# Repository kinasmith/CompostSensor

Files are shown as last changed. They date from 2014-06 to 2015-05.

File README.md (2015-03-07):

# Compost Sensor

> Compost Sensor is an open source sensor system for monitoring and recording the temperature and moisture of active compost. It is for small scale commercial composting operations to help with quality control and the certification processes.

This is a currently work in progress. Blog updates can be found [here](http://www.kinasmith.com/itp/spring2015/thesis/).

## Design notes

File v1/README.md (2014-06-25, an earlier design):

Wireless Temperature Sensor Network for logging and automating medium scale composting operations.

Communication uses the HopeRF RFM12B radio modules on a custom shield designed by Andy Sigler:
https://github.com/andySigler/PatchBay/tree/master/eagle/anodeShield

The structReceiverSD is the main receiver node for the network, taking in all of the sensor data from each node and logging into an SD card and displaying onto a LCD character display. 
It uses an Adafruit Datalogger shield with a modified CS Pin to avoid conflicting with the radio.

The structSender are the sender Nodes, Two versions are provided, which are practically identical currently. One for pushing down into an ATTiny84, and one that is designed to work for a regular Arduino. 

Some documentation currently lives here: 
http://kinasmith.com/compost-sensor

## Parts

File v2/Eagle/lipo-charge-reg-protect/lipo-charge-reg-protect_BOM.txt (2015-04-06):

Partlist exported from /Users/kina/Documents/eagle/thesis/lipo-charge-reg-protect.sch at 2/4/15 5:49 PM

Part Value                     Device                    Package            Description                                                                             PROD_ID     VALUE
C1   4.7uF                     0.1UF-25V(+80/-20%)(0603) 0603-CAP           CAP-00810                                                                               CAP-00810   0.1uF
C2   0.1uF                     0.1UF-25V(+80/-20%)(0603) 0603-CAP           CAP-00810                                                                               CAP-00810   0.1uF
C3   10uF                      0.1UF-25V(+80/-20%)(0603) 0603-CAP           CAP-00810                                                                               CAP-00810   0.1uF
C4   10uF                      0.1UF-25V(+80/-20%)(0603) 0603-CAP           CAP-00810                                                                               CAP-00810   0.1uF
J1                             JST_2MM_MALE              JST-2-SMD          Mates to single-cell LiPo batteries.                                                    CONN-08352       
JP1  pwrHdr2                   M02LOCK_LONGPADS          1X02_LOCK_LONGPADS Standard 2-pin 0.1" header. Use with                                                                     
JP2  dummerhdr                 M02LOCK_LONGPADS          1X02_LOCK_LONGPADS Standard 2-pin 0.1" header. Use with                                                                     
JP3  pwrHdr2                   M02LOCK_LONGPADS          1X02_LOCK_LONGPADS Standard 2-pin 0.1" header. Use with                                                                     
JP4  currentTestPoint          M02LOCK_LONGPADS          1X02_LOCK_LONGPADS Standard 2-pin 0.1" header. Use with                                                                     
LED1                           LED0603                   LED-0603           LEDs                                                                                                     
Q1   MOSFET-NCHANNELBSS123LT1G MOSFET-NCHANNELBSS123LT1G SOT23              Common NMOSFET Parts                                                                    TRANS-08345      
Q2   MOSFET-NCHANNELBSS138     MOSFET-NCHANNELBSS138     SOT23              Common NMOSFET Parts                                                                    TRANS-00830      
R1   220                       0OHM1/10W5%(0603)         0603               RES-08609                                                                               RES-08609   0    
R2   2k                        0OHM1/10W5%(0603)         0603               RES-08609                                                                               RES-08609   0    
R3   1k                        0OHM1/10W5%(0603)         0603               RES-08609                                                                               RES-08609   0    
U$1  USB-MINIB-5PIN            USB-MINIB-5PIN            USB-MINIB          Mini-USB "B" connector with 5th pin broken out.                                                          
U$2  MCP1700T-3002E/MB         MCP1700T-3002E/MB         SOT89              3.0V Low-Iq LDO - 250mA continuous current                                                               
U1   MCP73831                  MCP73831                  SOT23-5            Miniature single cell, fully integrated Li-Ion, Li-polymer charge management controller IC-09995         
U2                             S-8241                    SOT23-5L           Seiko S-8241

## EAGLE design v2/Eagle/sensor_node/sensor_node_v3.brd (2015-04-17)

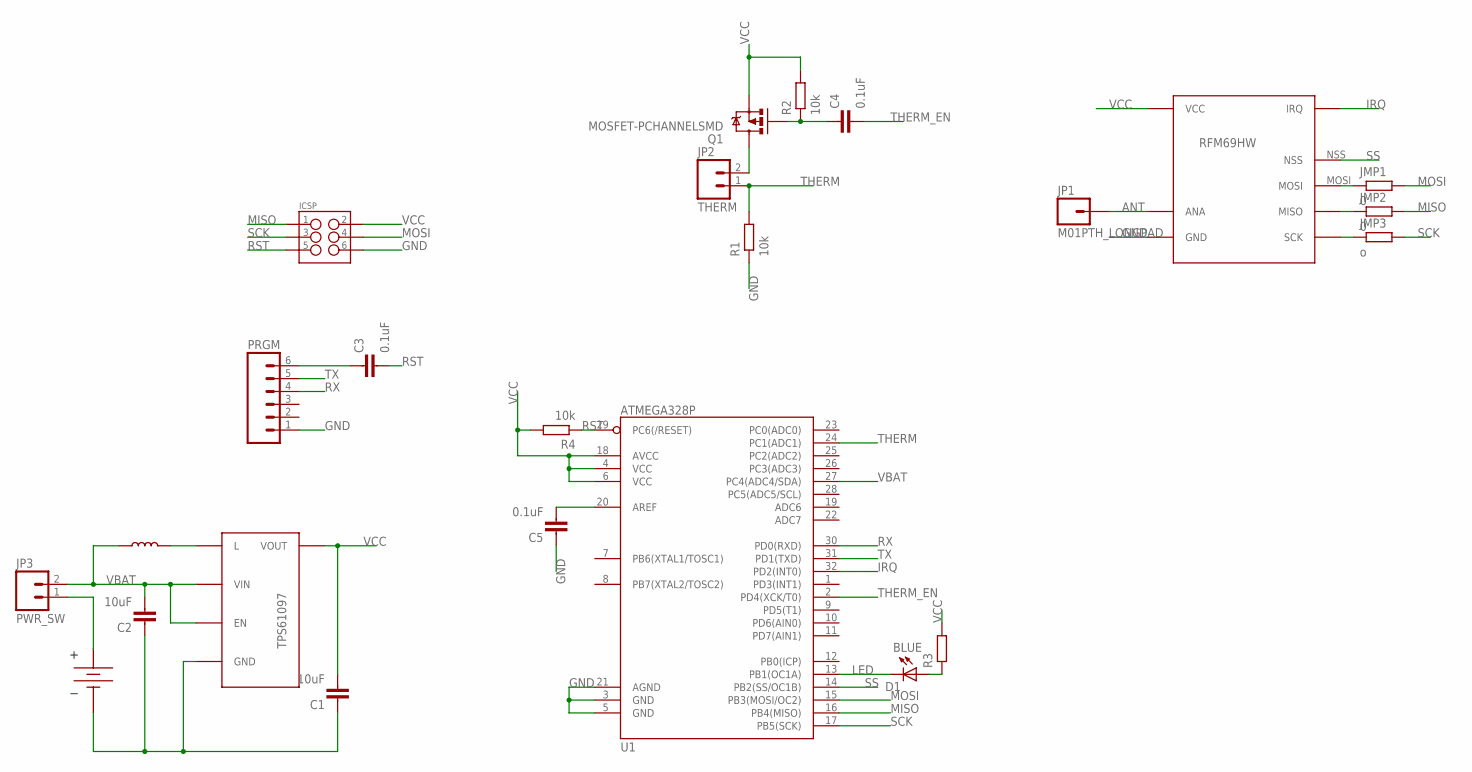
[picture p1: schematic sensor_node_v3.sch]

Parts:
C1, C2: 10uF; C0805-N
C3, C4, C5: 0.1uF; C0603-N
D1: BLUE; LED-0603
ICSP: M03X22X3_SILK_SM; 2X3
JMP1, JMP2: 0; R0805-L
JMP3: o; R0805-L
JP1: M01PTH_LONGPAD; 1X01_LONGPAD
JP2: THERM; 1X02_LONGPADS
JP3: PWR_SW; 1X02_LONGPADS
PRGM: M06LOCK_LONGPADS; 1X06_LOCK_LONGPADS
Q1: MOSFET-PCHANNELSMD; SOT23-3
R1, R2, R4: 10k; R0603-N
R3: RESISTOR0603-N; R0603-N
U1: ATMEGA328P; TQFP32-08
U$1: KEYSTONEAAHOLDER_2CELL
U$2: TPS61097-33; SOT23-5
U$3: COILCRAFT_DO3314
U$4: RFM69HW_MIN; RFM69

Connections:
ANT: JP1.1, U$4.ANA
GND: C1.1, C2.1, C5.1, ICSP.6, PRGM.1, R1.1, U1.3 (GND), U1.5 (GND), U1.21 (AGND), U$1.P$2 (GND), U$2.P$2 (GND), U$4.GND
IRQ: U1.32 (PD2(INT0)), U$4.DIO0 (IRQ)
LED: D1.C, U1.13 (PB1(OC1A))
MISO: ICSP.1, JMP2.2, U1.16 (PB4(MISO))
MOSI: ICSP.4, JMP1.2, U1.15 (PB3(MOSI/OC2))
unnamed: U$2.P$5 (L), U$3.P$1
unnamed: C3.1, PRGM.6
unnamed: D1.A, R3.1
unnamed: JMP1.1, U$4.MOSI
unnamed: JMP2.1, U$4.MISO
unnamed: JMP3.1, U$4.SCK
unnamed: JP3.1, U$1.P$1 (VBAT)
unnamed: C4.1, Q1.1 (G), R2.1
unnamed: C5.2, U1.20 (AREF)
unnamed: JP2.2, Q1.3 (D)
RST: C3.2, ICSP.5, R4.1, U1.29 (PC6(/RESET))
RX: PRGM.4, U1.30 (PD0(RXD))
SCK: ICSP.3, JMP3.2, U1.17 (PB5(SCK))
SS: U1.14 (PB2(SS/OC1B)), U$4.NSS
THERM: JP2.1, R1.2, U1.24 (PC1(ADC1))
THERM_EN: C4.2, U1.2 (PD4(XCK/T0))
TX: PRGM.5, U1.31 (PD1(TXD))
VBAT: C2.2, JP3.2, U1.27 (PC4(ADC4/SDA)), U$2.P$1 (VIN), U$2.P$3 (EN), U$3.P$2
VCC: C1.2, ICSP.2, Q1.2 (S), R2.2, R3.2, R4.2, U1.4 (VCC), U1.6 (VCC), U1.18 (AVCC), U$2.P$4 (VOUT), U$4.VCC

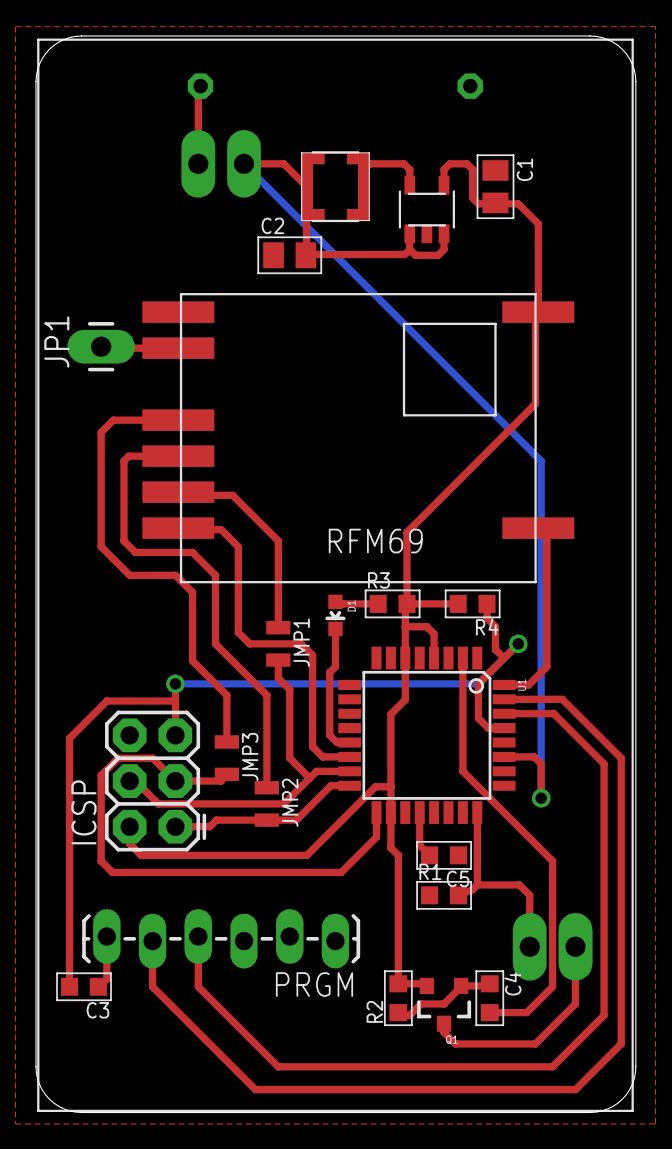
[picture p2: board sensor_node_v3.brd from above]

Board: 2 copper layers, 33.3 x 59.8 mm, 24 parts (0 on the bottom side), 25 nets.

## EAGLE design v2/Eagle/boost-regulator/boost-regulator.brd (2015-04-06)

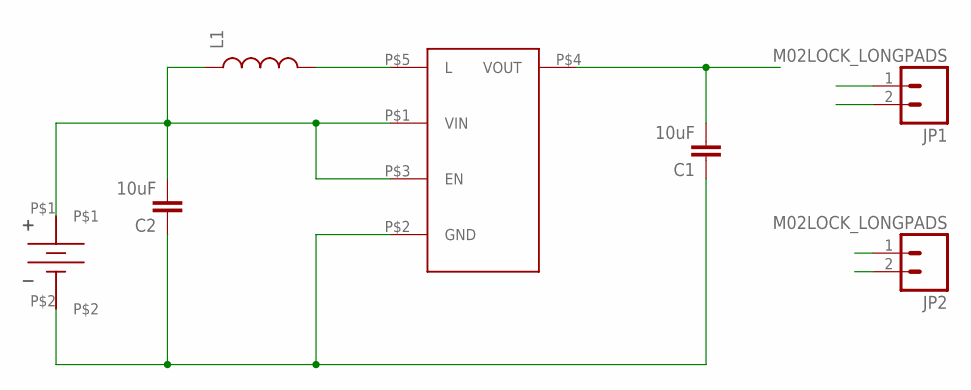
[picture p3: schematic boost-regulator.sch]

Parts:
C1, C2: 10uF; 0603-CAP
JP1, JP2: M02LOCK_LONGPADS; 1X02_LOCK_LONGPADS
L1: INDUCTOR0603; 0603
U$1: KEYSTONEAAHOLDER_2CELL
U$2: TPS61097-33; SOT23-5

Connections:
GND: C1.1, C2.1, JP1.2, JP2.2, U$1.P$2, U$2.P$2 (GND)
unnamed: L1.2, U$2.P$5 (L)
VCC: C1.2, JP1.1, JP2.1, U$2.P$4 (VOUT)
VIN: C2.2, L1.1, U$1.P$1, U$2.P$1 (VIN), U$2.P$3 (EN)

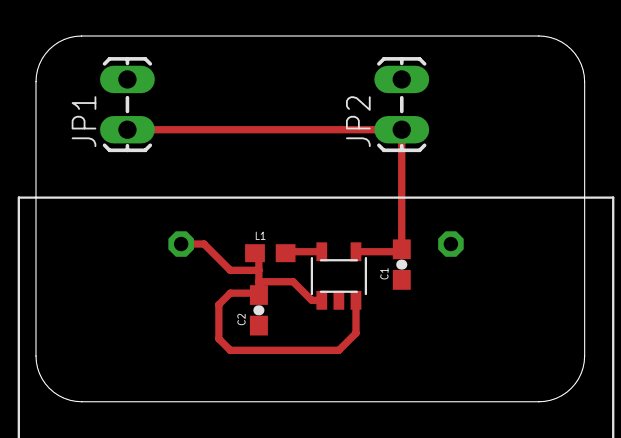
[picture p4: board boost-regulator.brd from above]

Board: 2 copper layers, 30.5 x 20.3 mm, 7 parts (0 on the bottom side), 4 nets.

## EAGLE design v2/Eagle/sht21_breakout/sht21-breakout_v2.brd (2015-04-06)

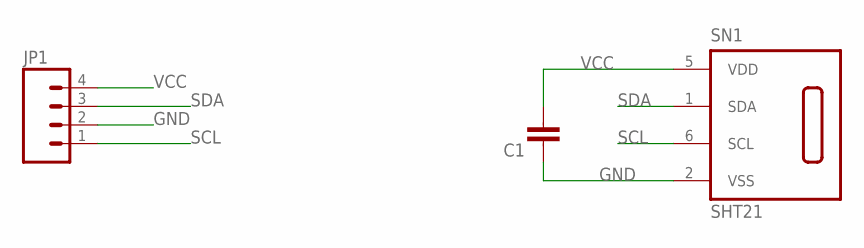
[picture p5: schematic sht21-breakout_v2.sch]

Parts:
C1: CAPACITOR0603-N; C0603-N
JP1: M04LONGPADS; 1X04_LONGPADS
SN1: SHT21; DFN6/SHT

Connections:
GND: C1.1, JP1.2, SN1.2 (VSS)
SCL: JP1.1, SN1.6 (SCL)
SDA: JP1.3, SN1.1 (SDA)
VCC: C1.2, JP1.4, SN1.5 (VDD)

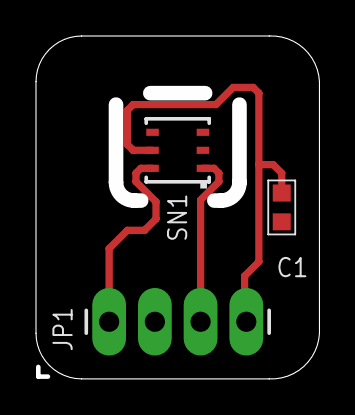
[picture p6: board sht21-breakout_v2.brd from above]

Board: 2 copper layers, 15.7 x 19.1 mm, 3 parts (0 on the bottom side), 4 nets.

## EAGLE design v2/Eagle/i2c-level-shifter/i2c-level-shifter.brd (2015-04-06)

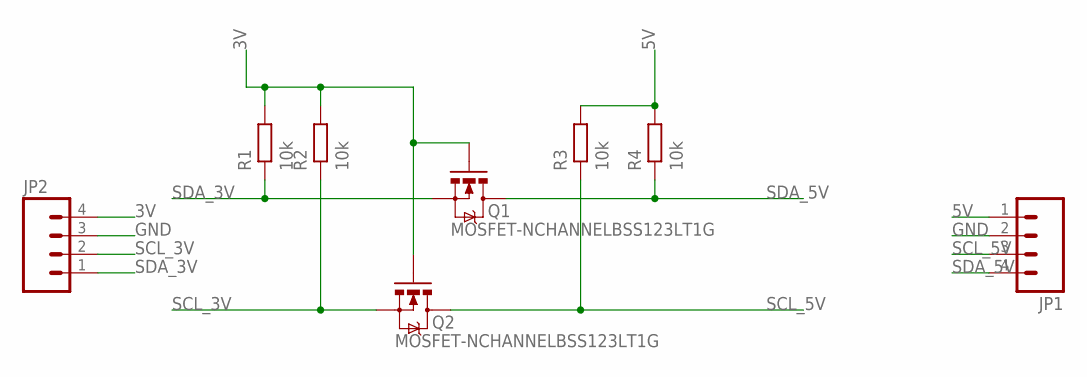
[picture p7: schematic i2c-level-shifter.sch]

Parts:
JP1, JP2: M04LOCK_LONGPADS; 1X04_LOCK_LONGPADS
Q1, Q2: MOSFET-NCHANNELBSS123LT1G; SOT23
R1, R2, R3, R4: 10k; R0603-N; MPN CRCW040210K0FKED

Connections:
3V: JP2.4, Q1.1 (G), Q2.1 (G), R1.2, R2.2
5V: JP1.1, R3.2, R4.2
GND: JP1.2, JP2.3
SCL_3V: JP2.2, Q2.2 (S), R2.1
SCL_5V: JP1.3, Q2.3 (D), R3.1
SDA_3V: JP2.1, Q1.2 (S), R1.1
SDA_5V: JP1.4, Q1.3 (D), R4.1

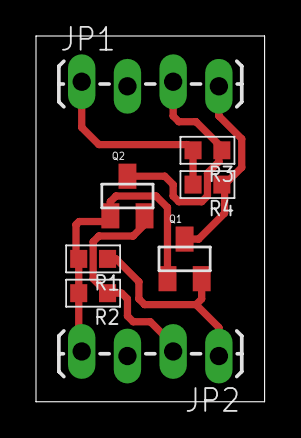
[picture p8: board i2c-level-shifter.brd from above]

Board: 2 copper layers, 12.7 x 20.3 mm, 8 parts (0 on the bottom side), 7 nets.

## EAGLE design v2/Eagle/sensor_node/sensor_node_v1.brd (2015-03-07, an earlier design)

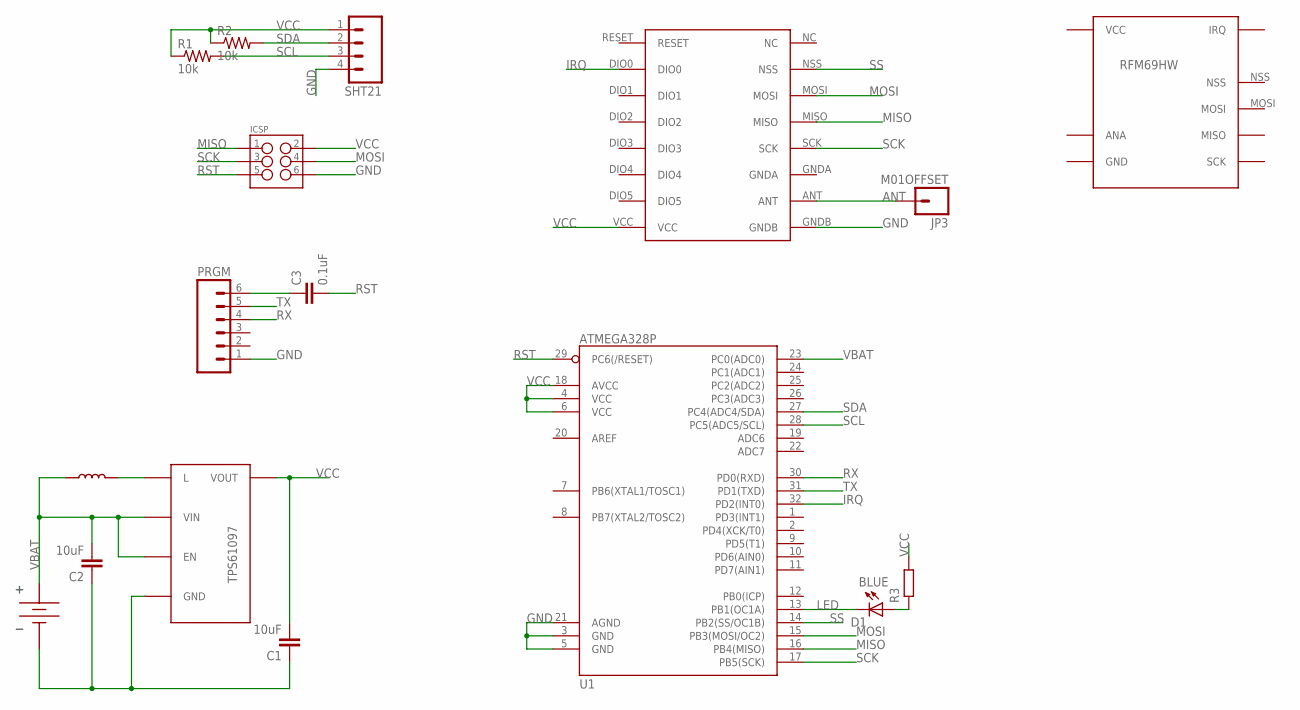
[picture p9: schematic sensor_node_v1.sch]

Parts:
C1, C2: 10uF; 0603-CAP
C3: 0.1uF; 0603-CAP
D1: BLUE; LED-0603
ICSP: M03X2FEMALE_SMD; 2X3_SMD
JP3: M01OFFSET; 1X01_OFFSET
PRGM: M06LOCK_LONGPADS; 1X06_LOCK_LONGPADS
R1, R2: 10k; 0603-RES
R3: RESISTOR0603-N; R0603-N
RFM69HW: RFM69HW; RFM
SHT21: M04LOCK_LONGPADS; 1X04_LOCK_LONGPADS
U1: ATMEGA328P; TQFP32-08
U$1: KEYSTONEAAHOLDER_2CELL
U$2: TPS61097-33; SOT23-5
U$3: COILCRAFT_DO3314
U$4: RFM69HW_MIN; RFM69

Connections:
ANT: JP3.1, RFM69HW.ANT
GND: C1.1, C2.1, ICSP.6, PRGM.1, RFM69HW.GNDB, SHT21.4, U1.3 (GND), U1.5 (GND), U1.21 (AGND), U$1.P$2 (GND), U$2.P$2 (GND)
IRQ: RFM69HW.DIO0, U1.32 (PD2(INT0))
LED: D1.C, U1.13 (PB1(OC1A))
MISO: ICSP.1, RFM69HW.MISO, U1.16 (PB4(MISO))
MOSI: ICSP.4, RFM69HW.MOSI, U1.15 (PB3(MOSI/OC2))
unnamed: U$2.P$5 (L), U$3.P$1
unnamed: C3.1, PRGM.6
unnamed: D1.A, R3.1
RST: C3.2, ICSP.5, U1.29 (PC6(/RESET))
RX: PRGM.4, U1.30 (PD0(RXD))
SCK: ICSP.3, RFM69HW.SCK, U1.17 (PB5(SCK))
SCL: R1.2, SHT21.3, U1.28 (PC5(ADC5/SCL))
SDA: R2.2, SHT21.2, U1.27 (PC4(ADC4/SDA))
SS: RFM69HW.NSS, U1.14 (PB2(SS/OC1B))
TX: PRGM.5, U1.31 (PD1(TXD))
VBAT: C2.2, U1.23 (PC0(ADC0)), U$1.P$1 (VBAT), U$2.P$1 (VIN), U$2.P$3 (EN), U$3.P$2
VCC: C1.2, ICSP.2, R1.1, R2.1, R3.2, RFM69HW.VCC, SHT21.1, U1.4 (VCC), U1.6 (VCC), U1.18 (AVCC), U$2.P$4 (VOUT)

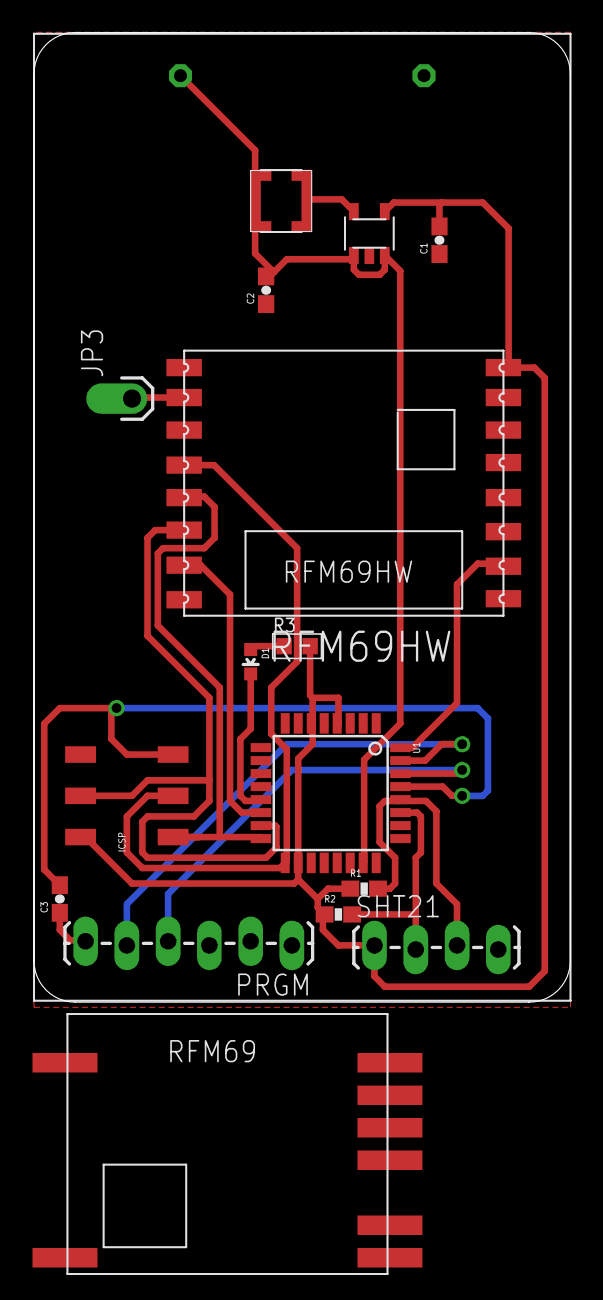
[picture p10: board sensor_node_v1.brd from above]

Board: 2 copper layers, 33.0 x 59.7 mm, 17 parts (0 on the bottom side), 18 nets.

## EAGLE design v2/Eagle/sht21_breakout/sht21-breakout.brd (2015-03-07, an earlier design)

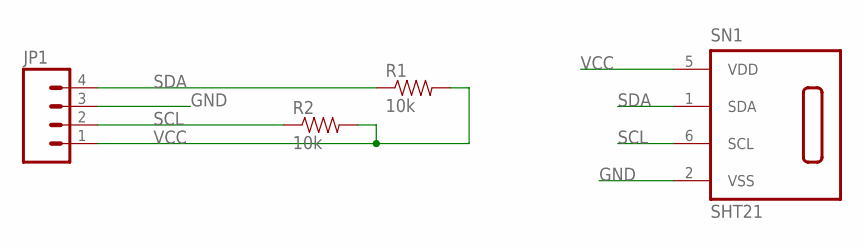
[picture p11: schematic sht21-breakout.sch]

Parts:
JP1: M04LONGPADS; 1X04_LONGPADS
R1, R2: 10k; 0603-RES
SN1: SHT21; DFN6/SHT

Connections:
GND: JP1.3, SN1.2 (VSS)
SCL: JP1.2, R2.1, SN1.6 (SCL)
SDA: JP1.4, R1.1, SN1.1 (SDA)
VCC: JP1.1, R1.2, R2.2, SN1.5 (VDD)

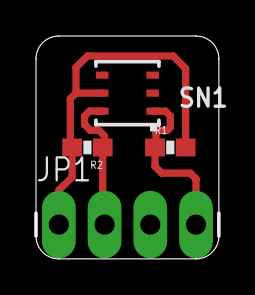
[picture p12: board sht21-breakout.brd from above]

Board: 2 copper layers, 10.2 x 12.4 mm, 4 parts (0 on the bottom side), 4 nets.

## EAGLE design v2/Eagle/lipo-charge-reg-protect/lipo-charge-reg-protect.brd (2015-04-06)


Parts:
C1: 4.7uF; 0603-CAP
C2: 0.1uF; 0603-CAP
C3, C4: 10uF; 0603-CAP
J1: JST_2MM_MALE; JST-2-SMD
JP1, JP3: pwrHdr2; 1X02_LOCK_LONGPADS
JP2: dummerhdr; 1X02_LOCK_LONGPADS
JP4: currentTestPoint; 1X02_LOCK_LONGPADS
LED1: LED0603; LED-0603
Q1: MOSFET-NCHANNELBSS123LT1G; SOT23
Q2: MOSFET-NCHANNELBSS138; SOT23
R1: 220; 0603
R2: 2k; 0603
R3: 1k; 0603
U1: MCP73831; SOT23-5
U2: S-8241; SOT23-5L
U$1: USB-MINIB-5PIN; USB-MINIB
U$2: MCP1700T-3002E/MB; SOT89

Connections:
GND: C1.1, C3.1, C4.1, JP1.1, JP3.1, Q2.2 (S), R2.1, R3.2, U1.2 (VSS), U$1.GND, U$1.MTN1 (MTN2), U$1.MTN2 (MTN3), U$1.MTN3 (MTN1), U$1.MTN4, U$2.1 (GND)
unnamed: LED1.C, U1.1 (STAT)
unnamed: LED1.A, R1.1
unnamed: R2.2, U1.5 (PROG)
unnamed: C2.1, J1.1 (-), Q1.2 (S), U2.3 (VSS)
unnamed: Q1.1 (G), U2.4 (DO)
unnamed: Q1.3 (D), Q2.3 (D)
unnamed: Q2.1 (G), U2.5 (CO)
unnamed: R3.1, U2.1 (VM)
unnamed: C4.2, JP4.2, U$2.3 (VOUT)
VBAT: C2.2, C3.2, J1.2 (+), U1.3 (VBAT), U2.2 (VDD), U$2.2 (VIN)
VCC: JP1.2, JP3.2, JP4.1
VIN: C1.2, R1.2, U1.4 (VIN), U$1.VBUS

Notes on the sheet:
Rset (R2) sets preconditioning, fast charge, and termination current limits. Iset = 1000 / Rset (A). Rset must be within 2.0k <= Rset <= 67k. Max charge current recommended is C/3, where C is battery capacity in mAh. Rset is shown for C = 1500 mAh: 1500 mAh / 3 hours = 500 mA, so Rset = 2.0k.


Board: 2 copper layers, 30.5 x 31.8 mm, 19 parts (0 on the bottom side), 13 nets.

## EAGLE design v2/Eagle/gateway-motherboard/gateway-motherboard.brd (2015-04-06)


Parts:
C1: 0.1uF; C0603-L
JP1: MOTE_LEFT; 1X13-LONGPADS
JP2: MOTE_RIGHT; 1X13-LONGPADS
JP3: FONA_HEADER; 1X12_LONGPADS
JP4: SWITCH; 1X02_LOCK_LONGPADS
JP5: DISPLAY; 1X04_LONGPADS
JP6: 5v; 1X01NS-KIT
Q1, Q2: N-MOSFET; SOT23
Q3: P-MOSFET; SOT23-3
R1, R2, R3, R4, R5, R6, R7: 10k; R0603-L
U$1: USB-MINIB; USB-MINIB_HOLE_RETENTION

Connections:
3V: JP1.11, JP3.1, Q1.1 (G), Q2.1 (G), R1.2, R2.2
5V: JP1.12, JP5.2, R3.2, R4.2, U$1.P1 (VBUS)
A0: JP1.1
A1: JP1.2
A2: JP1.3
A3: JP1.4, R5.1, R6.2
A6: JP1.7
A7: JP1.8
D2: JP2.2
D7: JP2.7, JP4.1
D8: C1.2, JP2.8
D9: JP2.9
D10: JP2.10
D11: JP2.11
D12: JP2.12
D13: JP2.13
D+: U$1.P3 (D+)
D-: U$1.P2 (D-)
FONA_RST: JP3.8
FONA_RX: JP2.3, JP3.3
FONA_TX: JP2.4, JP3.4
GND: JP1.13, JP3.11, JP4.2, JP5.1, R6.1, U$1.MNT1 (MTN1), U$1.MNT2 (MTN2), U$1.MNT3 (MTN3), U$1.MNT4 (MTN4), U$1.P5 (GND)
ID: U$1.P4 (ID)
KEY: JP2.5, JP3.6
unnamed: Q3.3 (D), R5.2
unnamed: C1.1, Q3.1 (G), R7.1
NS: JP3.2
PS: JP2.6, JP3.7
RI: JP3.5
RST: JP2.1
RX: JP1.9
SCL_3V: JP1.6, Q1.2 (S), R2.1
SCL_5V: JP5.3, Q1.3 (D), R4.1
SDA_3V: JP1.5, Q2.2 (S), R1.1
SDA_5V: JP5.4, Q2.3 (D), R3.1
SPKR+: JP3.10
SPKR-: JP3.9
TX: JP1.10
VBAT: JP3.12, JP6.1, Q3.2 (S), R7.2



Board: 2 copper layers, 76.2 x 52.1 mm, 18 parts (18 on the bottom side), 17 nets.

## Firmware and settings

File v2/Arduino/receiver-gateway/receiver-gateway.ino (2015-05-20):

#include <LiquidTWI.h>
#include <Wire.h>
#include <RFM69.h>
#include <SPI.h>
#include <SoftwareSerial.h>
#include <Bounce2.h>

#define NODEID      1
#define NETWORKID   100
#define FREQUENCY   RF69_433MHZ //Match this with the version of your Moteino! (others: RF69_433MHZ, RF69_868MHZ)
#define KEY         "thisIsEncryptKey" //has to be same 16 characters/bytes on all nodes, not more not less!
#define LED         9
#define SERIAL_BAUD 9600
#define ACK_TIME    30  // # of ms to wait for an ack

#define FONA_RX 3 //comms
#define FONA_TX 4 //comms
#define FONA_KEY 5 //powers board down
#define FONA_PS 6 //status pin. Is the board on or not?
#define FONA_RST 8 //FONA Reset
#define ATtimeOut  10000 //timeout for AT commands
#define keyTime 2000 // Time needed to turn on/off the Fona
#define NUM_FIELDS 7
#define NUM_NODES 4
#define BUTTON_PIN 7

LiquidTWI lcd(0);
RFM69 radio;
SoftwareSerial fonaSS = SoftwareSerial(FONA_TX, FONA_RX); //begin Software Serial
Bounce debouncer = Bounce(); 

/*==============|| FONA ||==============*/
String response; //globaly accessable response from AT commands (how do you make a function that returns a String?)
unsigned long Reporting = 60000 * 15;  // Time between uploads  //900 000 is 15 minutes
unsigned long LastReporting = 0;  // When did we last send data
float fonaVoltage = 0;

/*==============|| Data.Sparkfun ||==============*/
const String publicKey = ""; //Public Key
const String privateKey = ""; //Private Key
const String fieldNames[NUM_FIELDS] = {"id", "time", "temp", "humidity","voltage","rssi","gatewayvoltage"};
float fieldData[NUM_FIELDS];
float node00[NUM_FIELDS]={};
float node01[NUM_FIELDS]={};
float node02[NUM_FIELDS]={};
float node03[NUM_FIELDS]={};
float node04[NUM_FIELDS]={};
float* dataArray[]={&node00[0],&node01[0],&node02[0],&node03[0],&node04[0]};

/*==============|| Display & Buttons ||==============*/
unsigned long lcdReporting = 500; //time between updates
unsigned long lcdLastReporting = 0; 
unsigned long lcdBacklightLastReporting = 0; 
bool lcdBacklight;
bool gsmActive = 0;
byte buttonPushCounter = 0; //which sensor value is being displayed

/*==============|| RFM69 ||==============*/
byte ackCount=0;
const bool promiscuousMode = false; //set to 'true' to sniff all packets on the same network
typedef struct {    
  int nodeId; //store this nodeId
  unsigned long uptime; //uptime in ms
  float temp;
  float humidity;
  float voltage;
} Payload;
Payload theData;


void setup() {
  pinMode(FONA_PS, INPUT); 
  pinMode(FONA_KEY,OUTPUT);
  pinMode(FONA_RST, OUTPUT); 
  digitalWrite(FONA_KEY, HIGH);
  Serial.begin(9600);
  fonaSS.begin(9600);
  lcd.begin(16,2);
  lcd.setBacklight(1);
  pinMode(BUTTON_PIN,INPUT_PULLUP); //set button to input
  debouncer.attach(BUTTON_PIN);
  debouncer.interval(5); // interval in ms
  radio.initialize(FREQUENCY,NODEID,NETWORKID);
  radio.setHighPower(); //uncomment only for RFM69HW!
  radio.encrypt(KEY);
  Serial.println("Setup Done");
}

void loop() {
  /*==============|| Make GET Request ||==============*/
  //response = "";
  //doGSMStuff();

  if(!gsmActive) {
  /*==============|| RADIO Recieve ||==============*/
    if (radio.receiveDone()) {
      radioReceive();
      if (radio.ACKRequested()) {
        ACKsend();
      }
      Blink(LED,3);
    }
    updateButton();
    updateDisplay();
  }
}

void updateButton() {
  /*==============|| Button Input ||==============*/
  debouncer.update();
  if(debouncer.fell()) {
    lcd.clear(); //clear LCD on every button press
    if(lcdBacklight == 1) {
      buttonPushCounter++; //increment the pushCounter
      buttonPushCounter %= NUM_NODES; //if the push counter is greater than node#, roll back to 0
    } else {
      lcd.setBacklight(1);
      lcdBacklight = 1;
    }
    lcdBacklightLastReporting = millis();
  }
}
void updateDisplay() {
  /*==============|| Update Display ||==============*/
    if(lcdLastReporting + lcdReporting < millis()) {
      switch(int(dataArray[buttonPushCounter][0])) {
        case 10:
            lcd.setCursor(0,0); //sets cursor to the upper left corner to start
            lcd.print(int(dataArray[buttonPushCounter][0])); //prints currently viewed sensor number
            lcd.print(":");
            lcd.setCursor(0,1);
            lcd.print("T");
            lcd.print(dataArray[buttonPushCounter][2]); //print TEMP
            break;
        case 11:
            lcd.setCursor(0,0); //sets cursor to the upper left corner to start
            lcd.print(int(dataArray[buttonPushCounter][0])); //prints currently viewed sensor number
            lcd.print(": ");
            lcd.print("V");
            lcd.print(dataArray[buttonPushCounter][4]); //print Battery Voltage
            lcd.print("v");
            lcd.setCursor(0,1); //moves cursor to second line
            lcd.print("T");
            lcd.print(dataArray[buttonPushCounter][2]); //print TEMP
            lcd.print(" H");
            lcd.print(dataArray[buttonPushCounter][3]); //print Humidity: g/m^3
            break;
        case 12:
            lcd.setCursor(0,0); //sets cursor to the upper left corner to start
            lcd.print(int(dataArray[buttonPushCounter][0])); //prints currently viewed sensor number
            lcd.print(":");
            lcd.setCursor(0,1); //moves cursor to second line
            lcd.print("T");
            lcd.print(dataArray[buttonPushCounter][2]); //print TEMP
            lcd.print(" H");
            lcd.print(dataArray[buttonPushCounter][3]); //print Humidity: g/m^3
            break;
        case 13:
            lcd.setCursor(0,0); //sets cursor to the upper left corner to start
            lcd.print(int(dataArray[buttonPushCounter][0])); //prints currently viewed sensor number
            lcd.print(":");
            lcd.setCursor(0,1);
            lcd.print("Count: ");
            lcd.print(dataArray[buttonPushCounter][2]); //print TEMP
            break;
      }
      lcdLastReporting = millis();
    }
  if(lcdBacklightLastReporting + 30000 < millis()) { //lcd timeout
    lcd.setBacklight(0);
    lcdBacklight = 0;
  }
}
void radioReceive() {
  if(radio.DATALEN != sizeof(Payload)) {
    //Serial.print("Invalid payload received, not matching Payload struct!");
  }
  else {
    theData = *(Payload*)radio.DATA; //assume radio.DATA actually contains our struct and not something else
    int sensorNumber = theData.nodeId - 10;
    dataArray[sensorNumber][0] = theData.nodeId;
    dataArray[sensorNumber][1] = theData.uptime;
    dataArray[sensorNumber][2] = theData.temp;
    dataArray[sensorNumber][3] = theData.humidity;
    dataArray[sensorNumber][4] = theData.voltage;
    dataArray[sensorNumber][5] = radio.readRSSI();
    dataArray[sensorNumber][6] = fonaVoltage;
    /*
    Serial.print(theData.nodeId);
    Serial.print(", T:");
    Serial.print(theData.temp);
    Serial.print(", V:");
    Serial.print(theData.voltage);
    Serial.println();
    */
  }
}
void ACKsend(){
  //  byte theNodeID = radio.SENDERID;
  radio.sendACK();
  //Serial.print(" - ACK sent.");
  // When a node requests an ACK, respond to the ACK
  // and also send a packet requesting an ACK (every 3rd one only)
  // This way both TX/RX NODE functions are tested on 1 end at the GATEWAY
  if (ackCount++%3==0) {
    //   Serial.print(" Pinging node ");
    //Serial.print(theNodeID);
    //Serial.print(" - ACK...");
    delay(3); //need this when sending right after reception .. ?
    //    if (radio.sendWithRetry(theNodeID, "ACK TEST", 8, 0))  // 0 = only 1 attempt, no retries
    // Serial.print("ok!");
    // else Serial.print("nothing");
  }
}
void Blink(byte PIN, int DELAY_MS) {
  pinMode(PIN, OUTPUT);
  digitalWrite(PIN,HIGH);
  delay(DELAY_MS);
  digitalWrite(PIN,LOW);
}
void lcdprint(String toPrint){
  lcd.clear();
  lcd.print(toPrint);
}


void FONA_flushInput() {
    // Read all available serial input to flush pending data.
    uint16_t timeoutloop = 0;
    while (timeoutloop++ < 40) {
        while(fonaSS.available()) {
            Serial.write(fonaSS.read());
            timeoutloop = 0;  // If char was received reset the timer
        }
        delay(1);
    }
}
void turnOnFONA() { //turns FONA ON
    gsmActive = 1;
    if(!digitalRead(FONA_PS)) { //Check if it's On already. LOW is off, HIGH is ON.
        Serial.print("on");
      //lcdprint("FONA ON");
      digitalWrite(FONA_KEY,LOW); //pull down power set pin
      unsigned long KeyPress = millis(); 
      while(KeyPress + keyTime >= millis()) {} //wait two seconds
      digitalWrite(FONA_KEY,HIGH); //pull it back up again
    //  Serial.println("FONA Powered Up");
    } else //Serial.println("FONA Already On, Did Nothing");
    delay(5000); //delay for 10sec. NOTE: NEEDS to be longer than 3 seconds, 10 works great
    digitalWrite(FONA_RST, HIGH);
    delay(10);
    digitalWrite(FONA_RST, LOW);
    delay(100);
    digitalWrite(FONA_RST, HIGH);
    delay(7000);
}
void turnOffFONA() { //does the opposite of turning the FONA ON (ie. OFF)
    delay(2000); //This delay is also pretty important. Give it time to finish any operations BEFORE powering it down.
    if(digitalRead(FONA_PS)) { //check if FONA is OFF
        Serial.print("off ");
     // lcdprint("FONA OFF"); 
      digitalWrite(FONA_KEY,LOW);
      unsigned long KeyPress = millis();
      while(KeyPress + keyTime >= millis()) {}
      digitalWrite(FONA_KEY,HIGH);
     // Serial.println("FONA is Powered Down");
    }
    gsmActive = 0;
}
boolean sendATCommand(char Command[]) { //Send an AT command and wait for a response
  //response = "";
  FONA_flushInput();
  int complete = 0; // have we collected the whole response?
  char c; //capture serial stream
  String content; //place to save serial stream
  unsigned long commandClock = millis(); //timeout Clock
  fonaSS.println(Command); //Print Command
  while(!complete && commandClock <= millis() + ATtimeOut) { //wait until the command is complete
    while(!fonaSS.available() && commandClock <= millis()+ATtimeOut);
    while(fonaSS.available()) { //Collect the response
      c = fonaSS.read(); //capture it
      if(c == 0x0A || c == 0x0D); //disregard all new lines and carrige returns (makes the String matching eaiser to do)
      else content.concat(c); //concatonate the stream into a String
    }
    //Serial.println();
   // Serial.println(content); //Debug
    response = content; //Save it out to a global Variable (How do you return a String from a Function?)
    complete = 1;  //Label as Done.
  }
  if (complete ==1) {
    return 1; //Is it done? return a 1
  }
  else {
   // Serial.println("==> Command Timed Out");
   // Serial.println();
    return 0; //otherwise don't (this will trigger if the command times out) 
  }
}
void doHTTP() {
  //  Serial.print("HTTP Initialize: ");
  if(sendATCommand("AT+HTTPINIT")){ //initialize HTTP service. If it's already on, this will throw an Error. 
    //Serial.println(response);
  }
  //Serial.print("HTTPPARA, CID: ");
  if(sendATCommand("AT+HTTPPARA=\"CID\",1")){ //Mandatory, Bearer profile identifier
    //Serial.println(response);
  }
  //for each NODE listen above...
  for(int i=0; i < NUM_NODES; i++) { 
 //   Serial.print("First value of Array is: "); Serial.println(dataArray[i][0]);
    if(dataArray[i][0]>0) { //if first value is greater than 0...(ie. the node is more than 1, it exists/has data)
   //   Serial.print(">>> Transcribing Data for: ");
     // Serial.println(i);    
      //transfer data to holding array to send to URL
      for(int j=0; j < NUM_FIELDS; j++) { 
        fieldData[j] = dataArray[i][j];
        //dataArray[i][j] = 0; //clear array to it doesn't upload multiple repeat values
      }
    //  Serial.print("Set URL: "); 
      if(sendURL()){ //sets the URL for Sparkfun. Same result as the command above. Lots of other options, see the datasheet: sim800_series_at_command_manual
        //Serial.println(response);
      }
     // Serial.print("GET REQUEST: ");
      if(sendATCommand("AT+HTTPACTION=0")){ //make get request =0 - GET, =1 - POST, =2 - HEAD
        //Serial.println(response);
      }
      delay(2000); //wait for a bit for stuff to complete
     // Serial.print("HTTP Read: ");
      if(sendATCommand("AT+HTTPREAD")){ //Read the HTTP response and print it out
        lcdprint(response);
        //Serial.println(response);
      }
      delay(2000);//wait some more
     // Serial.print("Flush: ");
      FONA_flushInput();
      delay(1000);
    }
  }
 // Serial.print("HTTPTERM: ");
  if(sendATCommand("AT+HTTPTERM")){ //Terminate HTTP session. (You can make multiple HTTP requests while HTTPINIT is active. Maybe even to multiple URL's? I don't know)
  //  Serial.println(response);
  }
}
boolean sendURL() { //builds url for Sparkfun GET Request, sends request and waits for reponse
  int complete = 0;
  char c;
  String content;
  unsigned long commandClock = millis();                      // Start the timeout clock
  fonaSS.print("AT+HTTPPARA=\"URL\",\"");
  fonaSS.print("http://data.sparkfun.com/input/");
  fonaSS.print(publicKey);
  fonaSS.print("?private_key=");
  fonaSS.print(privateKey);
  for (int i_url=0; i_url<NUM_FIELDS; i_url++) {
    fonaSS.print("&");
    fonaSS.print(fieldNames[i_url]);
    fonaSS.print("=");
    fonaSS.print(fieldData[i_url]);
  }
  fonaSS.print("\"");
  fonaSS.println();
  while(!complete && commandClock <= millis() + ATtimeOut) {
    while(!fonaSS.available() && commandClock <= millis()+ATtimeOut);
    while(fonaSS.available()) {
      c = fonaSS.read();
      if(c == 0x0A || c == 0x0D);
      else content.concat(c);
    }
    response = content;
    complete = 1; 
  }
  if (complete ==1) return 1;
  else return 0;
}
void doGSMStuff() {
   if (LastReporting + Reporting < millis()) {
    lcd.setBacklight(0);
    radio.sleep(); //disable radio while updating GSM to save a little power
    lcdprint("fona ON");
    turnOnFONA(); //turn on board (sets gsmActive to 1)
    //Serial.print("Flush: "); 
    FONA_flushInput(); 
    //Serial.println();
   // Serial.print("Status: ");
    if(sendATCommand("AT")) {
      //Serial.println(response);
    }
    //Serial.print("Queitly: ");
    if(sendATCommand("ATE0")) {
      //Serial.println(response);
    } 
   // Serial.print("Battery: ");
    if(sendATCommand("AT+CBC")) {
      //+CBC: 0,66,3935OK
      delay(1000);
      //Serial.print(response); Serial.print(": ");
      fonaVoltage = response.substring(8,11).toFloat(); //changed this to add one more character. 100% was == to 10, not 100.
      //Serial.print(fonaVoltage); Serial.println("%");
    }
    //Serial.print("at+cgatt=0: ");
    if(sendATCommand("AT+CGATT=0")){ //Attach to GPRS service (1 - attach, 0 - disengage)
      //Serial.println(response);
    } 
   // Serial.print("at+cgatt=1: ");
    if(sendATCommand("AT+CGATT=1")){ //Attach to GPRS service (1 - attach, 0 - disengage)
      //Serial.println(response);
    }
    //AT+SAPBR - Bearer settings for applications based on IP
   // Serial.print("Connection Type: GPRS: ");
    if(sendATCommand("AT+SAPBR=3,1,\"CONTYPE\",\"GPRS\"")){ //3 - Set bearer perameters
      //Serial.println(response);
    }
    //Serial.print("Set APN: ");
    if(sendATCommand("AT+SAPBR=3,1,\"APN\",\"att.mvno\"")){ //sets APN for transaction
    //if(sendATCommand("AT+SAPBR=3,1,\"APN\",\"epc.tmobile.com\"")){ //sets APN for transaction
      //Serial.println(response);
    }
    //Serial.print("Open Bearer: ");
    if(sendATCommand("AT+SAPBR=1,1")) { //Open Bearer
      //Serial.println(response);
    }
    lcdprint("doHTTP()");
    doHTTP();
    //Serial.print("Disengage GPRS: ");
    if(sendATCommand("AT+SAPBR=0,1")){ //disengages the GPRS context.
      //Serial.println(response);
    }
    lcdprint("fona off");
    turnOffFONA(); //turn off module (sets gsmActive to 0)
    LastReporting = millis();
  }
}

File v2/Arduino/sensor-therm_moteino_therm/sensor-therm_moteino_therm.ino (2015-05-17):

#include <RFM69.h>
#include <SPI.h>
#include <jeelib-sleepy.h>

#define NODEID      10
#define NETWORKID   100
#define GATEWAYID   1
#define FREQUENCY   RF69_433MHZ //Match this with the version of your Moteino! (others: RF69_433MHZ, RF69_868MHZ)
#define KEY         "thisIsEncryptKey" //has to be same 16 characters/bytes on all nodes, not more not less!
#define LED         9
#define SERIAL_BAUD 9600
#define ACK_TIME    50  // # of ms to wait for an ack
#define NB_ATTEMPTS_ACK 5 //number of attempts to try before giving up

/****************************  STATIC VALUES FOR TEMPTERATURE INPUT AND CALCULATION  ****************************/
#define THERM_PIN A1   // The analoginput Pin for the Thermistor   
#define THERMISTORNOMINAL 10000      // Thermistor nominal resistance at 25 degrees C
#define TEMPERATURENOMINAL 25   // temp. for nominal resistance
#define NUMSAMPLES 5// how many samples to take and average (to smooth analog read values), more takes longer
#define BCOEFFICIENT 3950// The beta coefficient of the thermistor (usually 3000-4000)
#define SERIESRESISTOR 10000    // the value of the 'other' resistor
#define THERM_ENABLE 4 //therm read enable

#define V_BAT_PIN A4

//Variables for Battery Voltage
unsigned long bat_reporting;
unsigned long bat_last_reporting;
unsigned long while_bat_reporting;
boolean read_state = 0;

int thermVal = 0;

int TRANSMITPERIOD = 5000; //transmit a packet to gateway so often (in ms) (one minute)
int TRANSMITPERIOD_MINUTES = 1; //10 minute total
int ACK_FAIL_WAIT_PERIOD = 500; //30 seconds
float batteryVoltage;
boolean requestACK = true;
int numOfSends = 0;
RFM69 radio;

ISR(WDT_vect) { Sleepy::watchdogEvent(); } //set watchdog for Sleepy

typedef struct {    
    int nodeId; //store this nodeId
    unsigned long uptime; //uptime in ms
    float temp;
    float humidity;
    float voltage;
} Payload;
Payload payload;

void setup() {
    radio.initialize(FREQUENCY,NODEID,NETWORKID);
    radio.setHighPower(); //uncomment only for RFM69HW!
    radio.encrypt(KEY);
    radio.sleep();
    pinMode(THERM_ENABLE, OUTPUT);
    digitalWrite(THERM_ENABLE, LOW);
}

long lastPeriod = -1;

void loop() {
    int nAttempt = 0; //number of sends attempted
    bool flag_ACK_received = false; //is the acknowledgement recieved?
    float t = toF(getTemp(5)); //Get temp with 5 averaging AND Convert to Farenheit... 
    payload.nodeId = NODEID;
    payload.uptime = numOfSends;
    payload.temp = t;
    payload.humidity = 0.0; //Not sensing Humidity. Need a value for compatibilty with reciever and other sensors
    //payload.voltage = checkBatteryVoltage();
    payload.voltage = 0.0;
    while(nAttempt < NB_ATTEMPTS_ACK && !flag_ACK_received) { //resend package if it doesn't go through
        if (radio.sendWithRetry(GATEWAYID, (const void*)(&payload), sizeof(payload))){
            flag_ACK_received = true;
            Blink(LED, 100); //blink once for successful SEND
            numOfSends++;
        } else {
          radio.sendWithRetry(GATEWAYID, (const void*)(&payload), sizeof(payload));
          //Blink twice for Failed Send
          Blink(LED, 100);
          delay(100);
          Blink(LED, 100);
          delay(100);
          nAttempt++;
          Sleepy::loseSomeTime(ACK_FAIL_WAIT_PERIOD); //wait 30 seconds
        }
    }
    delay(100); //Let everything Finish before Sleeping
    radio.sleep(); //Sleep the Radio
    for(int i = 0; i < TRANSMITPERIOD_MINUTES; i++) { //Sleep the µC 
        Sleepy::loseSomeTime(TRANSMITPERIOD);
    }
}

int getTherm() {
  //gets Thermistor Value for future Math operations.
  //while_bat_reporting = millis(); //get current time
  //digitalWrite(THERM_ENABLE, HIGH); //set enable pin high (closes automatically within 20ms)
  //while(millis() < while_bat_reporting + 1000) { //read the value for 1 second
    thermVal = analogRead(THERM_PIN); //read the value
    //if(thermVal > 5) { //if the value goes HIGH the MOSFET has responded
      return thermVal; //return the Value and
     // break; //break out of the loop
   // }
   // bat_reporting = millis(); //set last time to current time
    //Forgot what this is for. Might be orphaned and uneeded?
    //if(bat_reporting >= bat_last_reporting+500 && read_state == 0) {
     // digitalWrite(THERM_ENABLE, HIGH);
      //read_state = 1; 
      //bat_last_reporting = bat_reporting; 
    //}
     // if(bat_reporting >= bat_last_reporting+250 && read_state == 1) { 
     // digitalWrite(THERM_ENABLE, LOW);  
      //read_state = 0;
     // bat_last_reporting = bat_reporting; 
   // }
 // }
}

float getTemp(int n_samples) {
  //do Thermistor readings and caclulations to turn resistance into temperature
  //this code was taken from the Adafruit tutorial:
  //https://learn.adafruit.com/thermistor/using-a-thermistor

  int samples[NUMSAMPLES];
  float result;
  float steinhart;
  // take N samples in a row, with a slight delay
  for (int i=0; i< n_samples; i++) {
    samples[i] = (abs(getTherm() - 1023));
    delay(10);
  }
  // average all the samples out
  result = 0;
  for (int i=0; i< NUMSAMPLES; i++) {
    result += samples[i];
  }
  result /= n_samples;
  result = 1023 / result - 1;
  result = SERIESRESISTOR / result;
  steinhart = result / THERMISTORNOMINAL;     // (R/Ro)
  steinhart = log(steinhart);                  // ln(R/Ro)
  steinhart /= BCOEFFICIENT;                   // 1/B * ln(R/Ro)
  steinhart += 1.0 / (TEMPERATURENOMINAL + 273.15); // + (1/To)
  steinhart = 1.0 / steinhart;                 // Invert
  steinhart -= 273.15;                         // convert to C
  return steinhart;
}

float toF(float temp) { //convert to F
  return temp * 9/5 + 32;
}

void Blink(byte PIN, int DELAY_MS) { //blink and LED
  pinMode(PIN, OUTPUT);
  digitalWrite(PIN,HIGH);
  delay(DELAY_MS);
  digitalWrite(PIN,LOW);
}

float checkBatteryVoltage() { //Check Battery Voltage
    int v = 0;
    for (int i = 0; i < 10; i++) {
        v += analogRead(V_BAT_PIN);
        delay(10);
    }
    //convert analog reading into actual voltage
    v = v/10; 
    batteryVoltage = (3.3 * v/1024.0); //this should be v/1023? 10 bit, 1024 values, 0-1023
    return batteryVoltage; //return value
}

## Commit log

2014-06-24 Copied code over to non-84 fileand changed to work with normal arduino
2014-06-24 fixed a missing semicolon in the LCD startup
    [structReceiverSD.ino]
2014-06-25 added eagle Sch. files
    [receiverNode_Uno.sch, senderNode_Uno.sch]
2014-06-25 moved Arduino code to Arduino Folder
2014-06-25 added tiny84 senderNode schematic and board
    [senderNode_tiny84.brd, senderNode_tiny84.sch]
2015-03-07 initial commit of version 2 materials
    [receiverNode_Uno.sch, senderNode_Uno.sch, senderNode_tiny84.brd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]
2015-03-11 Big Edit. Cleaned up a lot of wasted Serial Print space, added Display and Button code. Display Timeout and etc. Struggled for a long time on issues that were related to the sketch being too big for 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
    [structReceiverSD.ino]
2015-03-24 Spring Break test
2015-03-26 changed sleepy library in sensor node
2015-03-26 implemented the Bounce2 Library, moved the Button and screen update code to seperate functions
2015-03-31 added back in Serial.print's for debug
2015-03-31 switch to other branch
2015-04-01 updated ALL of the sensor nodes
2015-04-06 added more circuits to v2/eagle
    [328_smt_testing.brd, 328_smt_testing.sch, 328p-DIP-ISP-adapter.brd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]
2015-04-17 added sensorNode_v3 eagle board and updated sensor codes. Keys now live in a ._key file, which is not pushed
    [328_smt_testing.brd, 328_smt_testing.sch, 328p-DIP-ISP-adapter.brd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]
2015-04-19 changed the analog read pin for VBAT
2015-04-23 added comments to sensor-therm
2015-05-17 finished modifications, added moteino versions of the sensor node for thermistor and dht22
2015-05-17 added vibration sensor
2015-05-17 modified to display only relevent data from sensors
2015-05-20 modified to include SHT21 probe in demonstration

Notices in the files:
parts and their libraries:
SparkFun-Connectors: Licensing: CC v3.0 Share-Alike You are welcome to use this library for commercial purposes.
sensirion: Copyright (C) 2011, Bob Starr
